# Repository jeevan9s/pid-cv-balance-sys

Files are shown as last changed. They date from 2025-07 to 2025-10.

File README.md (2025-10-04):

# PID-OpenCV Ball Balancing Platform
> Control system leveraging PID & computer vision to balance a ball on a platform.

**WIP**: PID tuning is ongoing. Final results will be added soon.

<details>
<summary>Contents</summary>

- [Overview](#overview)
- [Architecture](#architecture)
  - [Firmware](#firmware)
  - [Hardware](#hardware)
- [Prerequisites / Installation](#prerequisites--installation)
- [Contact](#contact)

</details>

# Overview
<table width="100%" cellspacing="0" cellpadding="0">
  <tr>
    <td width="50%">
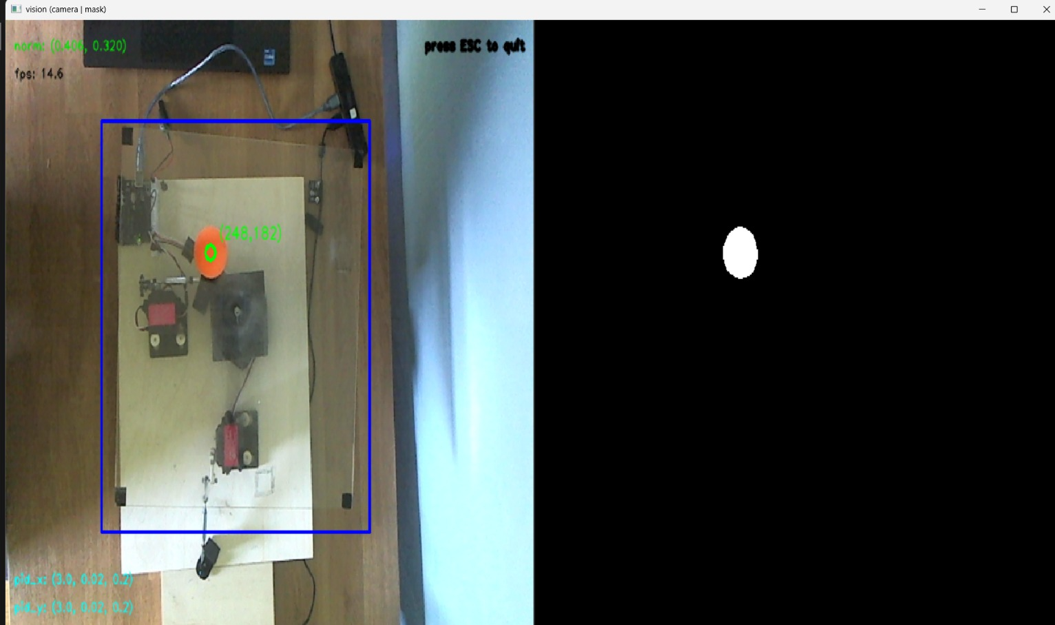
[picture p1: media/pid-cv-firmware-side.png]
      
    </td>
    <td width="50%">
      
    </td>
  </tr>
</table>

I built this project to learn and apply control theory and system design (PID), and embedded image processing (openCV).

The system's main function is to balance a ball by using computer vision to extract its coordinates relative to a user-selected region of interest (ROI). These coordinates are then sent to a control module that computes the correctional Servo angles for both axes. The system's firmware was coded in a mix of Python and Arduino. 

## Built With
- 
- 
- 
- 

# Architecture
## System
<div align="center">
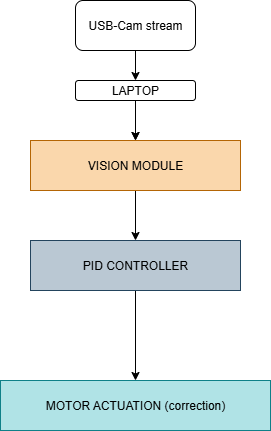
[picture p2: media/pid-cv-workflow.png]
      
</div>

The system's design is _modular_, it conists of three sections:
<details>
  <summary><a href="/media/pid-cv-vision-workflow.png" target="_blank">Vision</a></summary>
  <p>
    This module processes the webcam stream, and detects, tracks, and returns the ball's positional coordinates.
  </p>

  <ul>
    <li>ROI Selection, HUD Creation</li>
    <li>Object Binarization, Gaussian Blur, Colour Masking, Contour Detection /li>
    <li>ROI-Relative Position Extraction (coords)</li>
  </ul>
</details>

<details>
  <summary><a href="/media/pid-cv-control-workflow.png" target="_blank">Control</a></summary>
  <p>
    The control module computes the motor correction angles with the ball's positional coordinates via the PID algorithm/equation.
  </p>

  <ul>
    <li>Compute correctional angles with PID on each axis (2 controllers)</li>
    <li>Convert to servo-writeable angles</li>
  </ul>
</details>

<details>
  <summary><a href="/media/pid-cv-actuation-workflow.png" target="_blank">Actuation</a></summary>
  <p>
    The actuation module receives the correction angles, applies smoothing, and writes to each axis motor.
  </p>

  <ul>
    <li>Read incoming serial data from Python-side (correction angles)</li>
    <li>Smooth and write angles to each motor (X and Y)</li>
  </ul>
</details>

## Firmware 
System was written in Python and Arduino, using <a href="https://pypi.org/project/pyserial/">pyserial</a> to connect  both sides. 

Code workflow consists of user selection of the ROI (region of interest), ball binarization, detection, and position extraction. Positions are then sent to the control script to calculate the correctional angles which are sent to the Arduino side via serial to be smoothed and applied to each motor. 

- The PID parameters along with any scaling/smoothing factors are tuned to optimized the system.

As seen in the <a href="/firmware/python/">Python</a> directory within <a href="/firmware/">Firmware</a>, there are code modules responsible for each step (vision, pid, serial, etc.). 

 **Here's an example of a vision module function:**

<details>
  <summary>binarize_ball()</summary>

```py
# this function is used to "binarize" the ball, converting the ball region into a clean binary mask by highlighting the ball based on its color (orange in my case).

def _binarize_ball(self, roi_bgr):
    # colour masking
    blurred = cv2.GaussianBlur(roi_bgr, (5,5), 0)
    hsv = cv2.cvtColor(blurred, cv2.COLOR_BGR2HSV)

    lower = np.array([0, 120, 120])
    upper = np.array([25, 255, 255])
    mask = cv2.inRange(hsv, lower, upper)

    # cleaning 
    mask = cv2.morphologyEx(mask, cv2.MORPH_OPEN, self.kernel)
    mask = cv2.morphologyEx(mask, cv2.MORPH_CLOSE, self.kernel)

    return mask
```
</details>

**A snippet from the Arduino (actuation) module:**

<details>
<summary>handleServoCommand()</summary>

```cpp
// this functions takes the command (angles) sent by the Python side via serial, applies smoothing, and writes them to the motors. 

void handleServoCommand(String command) {
  int spaceIndex = command.indexOf(' ');
  if (spaceIndex == -1) return;  

  int angleX = command.substring(0, spaceIndex).toInt();
  int angleY = command.substring(spaceIndex + 1).toInt();

  smoothedX = alpha * angleX + (1 - alpha) * smoothedX;
  smoothedY = alpha * angleY + (1 - alpha) * smoothedY;

  SERVO_X.write(int(smoothedX));
  SERVO_Y.write(int(smoothedY));
}
```
</details>

## Hardware 
The system's hardware can be broken down into electrical and mechanical components. 
<br>
- The electric components feature an ELEGOO Uno R3 MCU for central control (serial, angle writing), and two 20kg DS3218 Servo motors; all powered by 6V 2A power from an AC Adapter.

- The mechanical components were mostly custom designed and 3D-Printed with Fusion360. These include a rising bracket/mount for the Servos, L-brackets to connect the Servo arms to the platform, and the system's central base. The acrylic platform was purchased seperately and drilled through for connection.

## Prerequisites / Installation

### Prerequisites

- Arduino IDE: with board support for your MCU
- Python environment
- pip for Python

### Installation & Usage

1. Clone the repository:
```bash
git clone https://github.com/jeevan9s/pid-cv-balance-sys.git
cd pid-cv-balance-sys
```

2. Install Python dependencies:
```bash
pip install -r requirements.txt
```

3. Upload the Arduino sketch to your microcontroller using the Arduino IDE. Make sure the correct board and port are selected.

4. Run the main script:
```bash
python main.py
```
5. Select an ROI manually with your cursor and tune parameters in <a href="/firmware/python/config.py">config file</a> according to the observed behaviour.
<br>
thanks for reading!
<br>

## Contact 
[`email`](mailto:jeevansanchez42@gmail.com)&nbsp;&nbsp;&nbsp; [``LinkedIn``](https://linkedin.com/in/jeevansanchez)

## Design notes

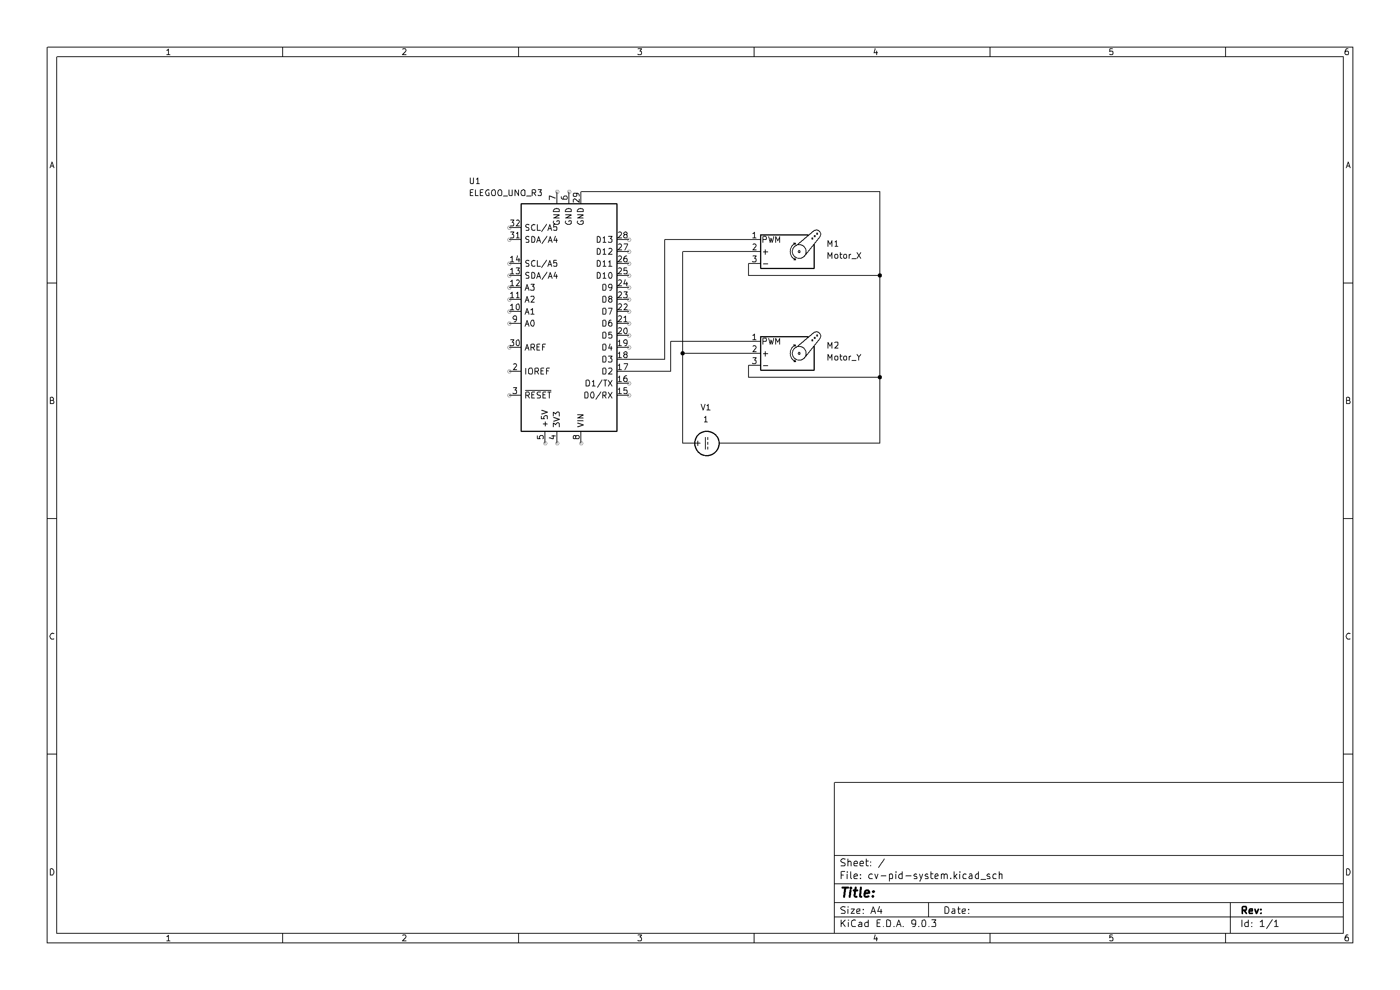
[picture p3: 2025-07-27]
media/pid-cv-schematic.png

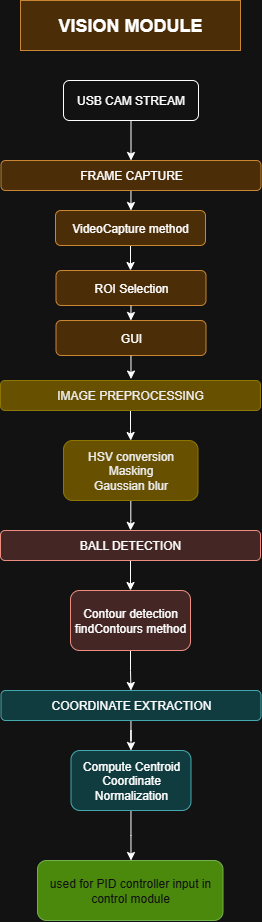
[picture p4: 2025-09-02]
media/pid-cv-vision-workflow.png

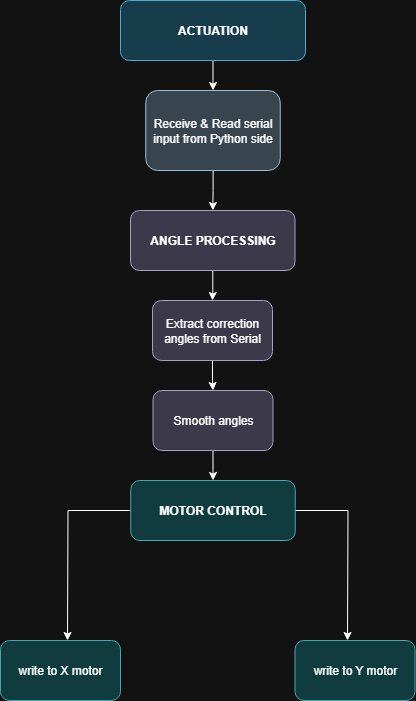
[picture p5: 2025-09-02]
media/pid-cv-actuation-workflow.png

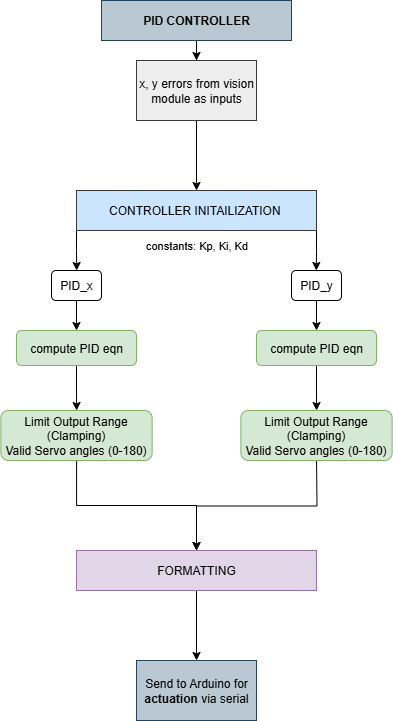
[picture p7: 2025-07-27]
media/pid-cv-control-workflow.png

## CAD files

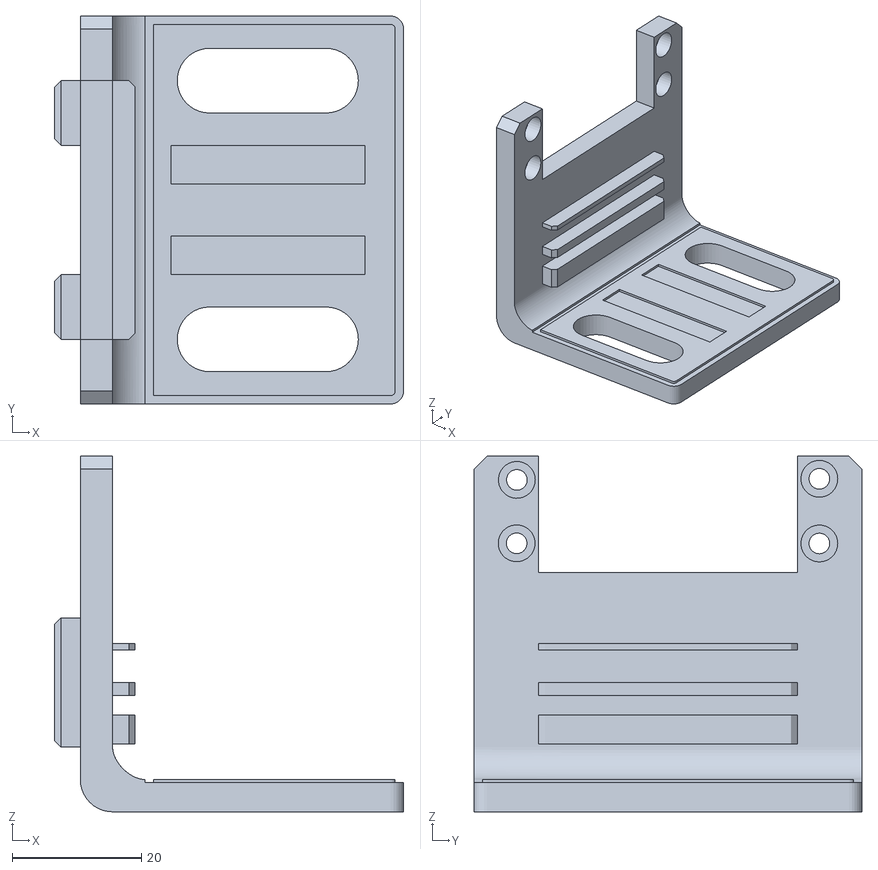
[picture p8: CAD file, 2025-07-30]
cad/pid-cv-servo-riser v7.stl
54.0 x 60.0 x 55.0

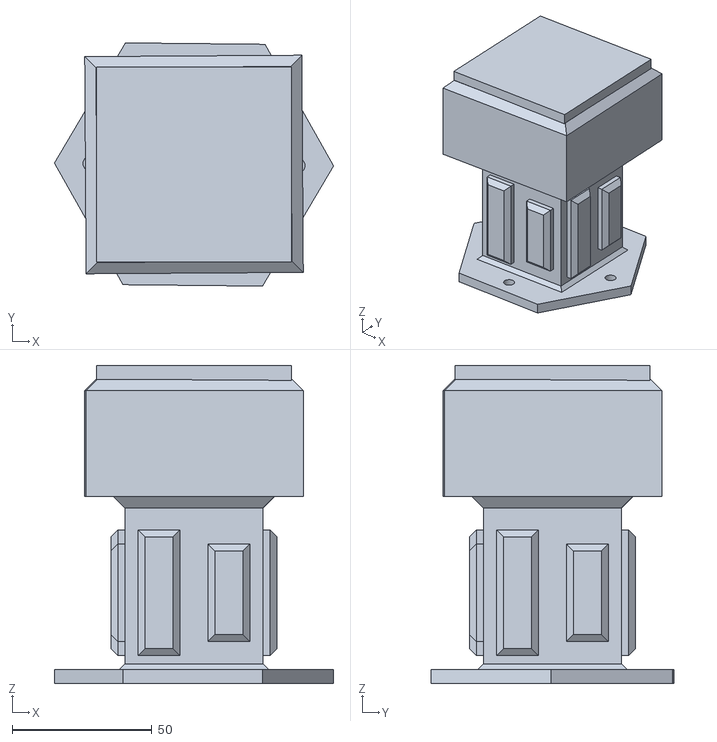
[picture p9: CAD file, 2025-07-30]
cad/pid-cv-support-beam-y v4.stl
100.0 x 87.1 x 113.9

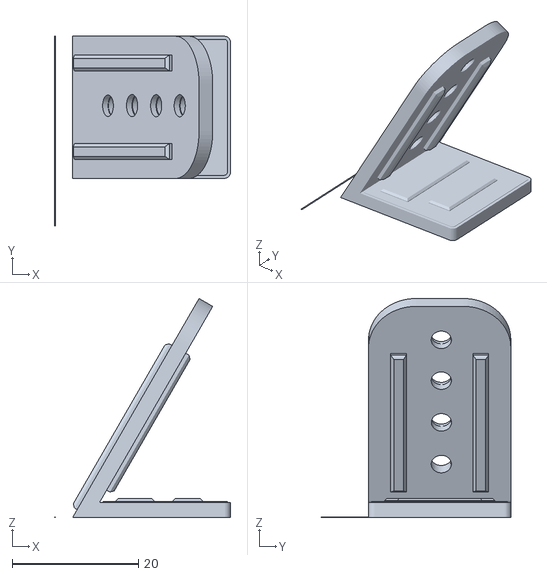
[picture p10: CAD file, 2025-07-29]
cad/pid-cv-platform-bracket v3.stl
27.9 x 30.0 x 34.6

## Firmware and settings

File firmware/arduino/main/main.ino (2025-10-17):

#include <Servo.h>
#include "config.h"

// init
Servo SERVO_X;
Servo SERVO_Y;

String inputString = "";
bool stringComplete = false;

float smoothedX = SERVO_X_NEUTRAL;
float smoothedY = SERVO_Y_NEUTRAL;
const float alpha = ALPHA;

void setup() {
    Serial.begin(BAUD_RATE);
    SERVO_X.attach(SERVO_X_PIN);
    SERVO_Y.attach(SERVO_Y_PIN);

    inputString.reserve(32);
    Serial.println("arduino-side ready.");

    // initPlatform();
}

void loop() {
    readSerial();
    if (stringComplete) {
        handleServoCommand(inputString);
        inputString = "";
        stringComplete = false;
    }
}

// -------- HELPERS --------

void smoothMove(Servo &servo, float startAngle, float endAngle, int durationMs) {
    const int steps = 10; 
    float stepDelay = float(durationMs) / steps;
    float stepSize = (endAngle - startAngle) / steps;

    for (int i = 0; i <= steps; i++) {
        servo.write(startAngle + stepSize * i);
        delay(stepDelay);
    }
}
void initPlatform() {

    smoothMove(SERVO_X, SERVO_X_NEUTRAL, SERVO_X_MIN, 300);
    smoothMove(SERVO_Y, SERVO_Y_NEUTRAL, SERVO_Y_MIN, 300);
    delay(300);

    smoothMove(SERVO_X, SERVO_X_MIN, SERVO_X_MAX, 300);
    delay(300);

    smoothMove(SERVO_Y, SERVO_Y_MIN, SERVO_Y_MAX, 300);
    delay(300);

    smoothMove(SERVO_X, SERVO_X_MAX, SERVO_X_MIN, 300);
    delay(300);

    smoothMove(SERVO_Y, SERVO_Y_MAX, SERVO_Y_NEUTRAL, 300);
    smoothMove(SERVO_X, SERVO_X_MIN, SERVO_X_NEUTRAL, 300);
}

// ----- READ SERIAL -----
void readSerial() {
    while (Serial.available()) {
        char inChar = (char)Serial.read();
        if (inChar == '\n') {
            stringComplete = true;
        } else {
            inputString += inChar;
        }
    }
}

// ----- ACTUATION -----
void handleServoCommand(String command) {
    int spaceIndex = command.indexOf(' ');
    if (spaceIndex == -1) return;  

    int angleX = command.substring(0, spaceIndex).toInt();
    int angleY = command.substring(spaceIndex + 1).toInt();

    angleX = constrain(angleX, SERVO_X_MIN, SERVO_X_MAX);
    angleY = constrain(angleY, SERVO_Y_MIN, SERVO_Y_MAX);

    smoothedX = alpha * angleX + (1 - alpha) * smoothedX;
    smoothedY = alpha * angleY + (1 - alpha) * smoothedY;

    SERVO_X.write(int(smoothedX));
    SERVO_Y.write(int(smoothedY));
}

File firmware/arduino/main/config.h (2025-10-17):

// arduino config 

#ifndef CONFIG_H
#define CONFIG_H

/* SERVO PINS
 ---------------- */
 #define SERVO_X_PIN 4
 #define SERVO_Y_PIN 2

 #define ALPHA 0.95

/* SERVO POS
 ---------------- */
#define SERVO_X_NEUTRAL 40
#define SERVO_Y_NEUTRAL 95

#define SERVO_X_MAX 250
#define SERVO_X_MIN 20
#define SERVO_Y_MAX 250
#define SERVO_Y_MIN 20


#define BAUD_RATE 115200
#endif

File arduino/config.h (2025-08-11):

// arduino config 

#ifndef CONFIG_H
#define CONFIG_H

/* SERVO PINS
 ---------------- */
 #define SERVO_X_PIN 2
 #define SERVO_Y_PIN 4


/* SERVO POS
 ---------------- */
#define SERVO_X_NEUTRAL 135
#define SERVO_Y_NEUTRAL 135

#define SERVO_X_MAX 160
#define SERVO_X_MIN 100
#define SERVO_Y_MAX 160
#define SERVO_Y_MIN 100


#define BAUD_RATE 115200
#endif

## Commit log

2025-07-27 add pid controller workflow
2025-07-27 add schematic
2025-07-28 add servo riser stl
    [pid-cv-servo-riser v6.stl]
2025-07-29 add platform bracket
    [pid-cv-platform-bracket v3.stl]
2025-07-30 add vertical support beam
    [pid-cv-support-beam-y v4.stl]
2025-07-30 add servo riser v7
    [pid-cv-servo-riser v7.stl]
2025-08-18 wrote pid controller
2025-08-18 main arduino side
2025-08-30 Rename pid-cv-actuation-workflow.drawio (2).png to 2pid-cv-actuation-workflow.drawio.png
2025-09-01 tuned - adjust ball mass (inertia/physics problem)
    [config.h]
2025-10-17 fix serial namespace bug
    [config.h, main.ino]
